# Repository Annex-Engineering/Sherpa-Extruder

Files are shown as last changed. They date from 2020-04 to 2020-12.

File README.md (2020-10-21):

# Sherpa - Release 1

This is the Sherpa Extruder, a ground up design developed by Anlin and the team at Annex Engineering. It's a family of dual geared hobbed filament extruders designed for use with any printer. They features a 6:1 gear driven design to provide torque while being able to be near silent. You must perform your own tuning to get the best results.

Our discord server can be found here: https://discord.gg/MzTR3zE

The BOM and Sourcing Guide for this product can be found here: https://docs.google.com/spreadsheets/d/1O3eyVuQ6M4F03MJSDs4Z71_XyNjXL5HFTZr1jsaAtRc/edit?usp=sharing

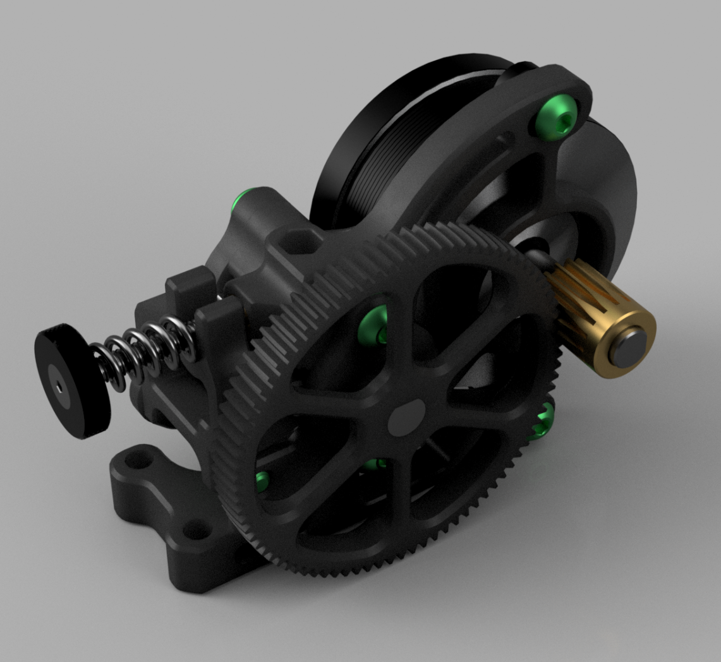
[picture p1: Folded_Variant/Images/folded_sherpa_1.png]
Image of Sherpa Extruder

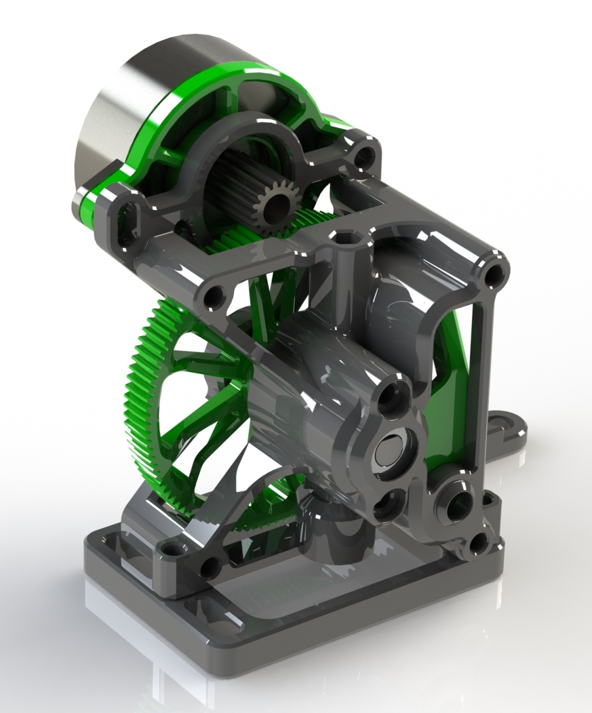
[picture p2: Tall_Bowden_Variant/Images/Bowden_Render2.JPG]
Image of Sherpa Extruder


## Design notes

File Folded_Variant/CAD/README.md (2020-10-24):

# Sherpa Folded

 - 103t was never really publicly released, but we are giving you the cad anyways. Consider it in a rough state
 
 - 85t is the actual final release 1, it is smaller and better in every way.

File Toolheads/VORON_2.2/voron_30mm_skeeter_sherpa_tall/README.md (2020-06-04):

This toolhead is for the Sherpa Standard Direct Drive Toolhead

30mm cooling fan for the mosquito

- requires 5 short m3 heat inserts

- Uses m3x30 screws to hold the fan and ducts on

- Uses same m2 plastite screws and fans from the original toolhead for the ducts

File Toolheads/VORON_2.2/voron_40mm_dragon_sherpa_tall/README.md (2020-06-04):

This toolhead is for the Sherpa Standard Direct Drive Toolhead

40mm cooling fan for the Dragon Hotend

- requires 5 short m3 heat inserts

- Uses m3x30 screws to hold the fan and ducts on

- Uses same m2 plastite screws and fans from the original toolhead for the ducts

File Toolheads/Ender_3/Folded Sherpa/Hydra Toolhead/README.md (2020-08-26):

# Ender 3 - Hydra Mount - Folded Sherpa Edition

This is a simple adaption of the head-part of the [Hydra Fanduct](https://www.thingiverse.com/thing:4062242) to fit a Folded Sherpa on the toolhead. 
Two versions exist - one for just the folded sherpa and a second version with additional support for a [carabiner-toolboard](https://github.com/Annex-Engineering/Annex_Engineering_PCBs/tree/master/carabiner-toolboard)

# Mounting Hardware

The following parts are required to mount a folded Sherpa on the head:
- 2x Heatset Inserts (M3xL4.0xD5.0)
- 1x M3x12mm Screw
- 1x M3x10mm Screw

The following parts are required in addition to the ones above mounting the carabiner on the mount:
- 2x Heatset Inserts (M3xL4.0xD5.0)
- 2xM3x8mm Screws (6mm are also ok)

# Adapting the .step files
Both versions of the toolhead have a .step / f3z-file provided to allow for simple adaption. 
The following parameters are intended to be adapted:
- HeatsetDiameter: Diameter of your heatset-inserts. If printing in ABS simpy insert the diameter of your heatset-inserts, otherwise substract 0.2mm
- ScrewHeadDiameter: Diameter of the countersunk screws. Provided 6mm is for m3 buttonhead screws
- ScrewHeadDepth: Depth for the countersunk screws. Provided 2mm is for m3 buttonhead screws.

## Attribution

The head is based & intended to be used with the great [Hydra Fanduct](https://www.thingiverse.com/thing:4062242) on an Ender3, designed by [BoothyBoothy](https://www.thingiverse.com/boothyboothy/designs)

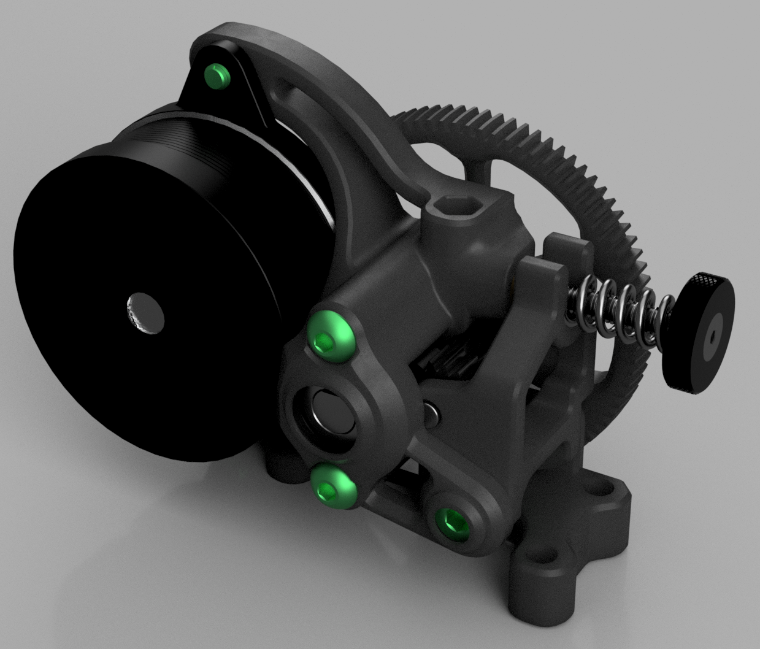
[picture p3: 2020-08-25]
Folded_Variant/Images/folded_sherpa_2.png

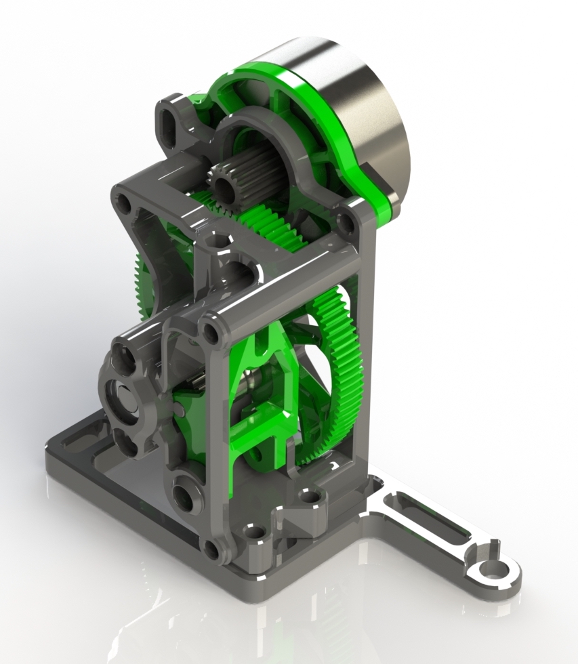
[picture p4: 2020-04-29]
Tall_Bowden_Variant/Images/Bowden_Render1.JPG

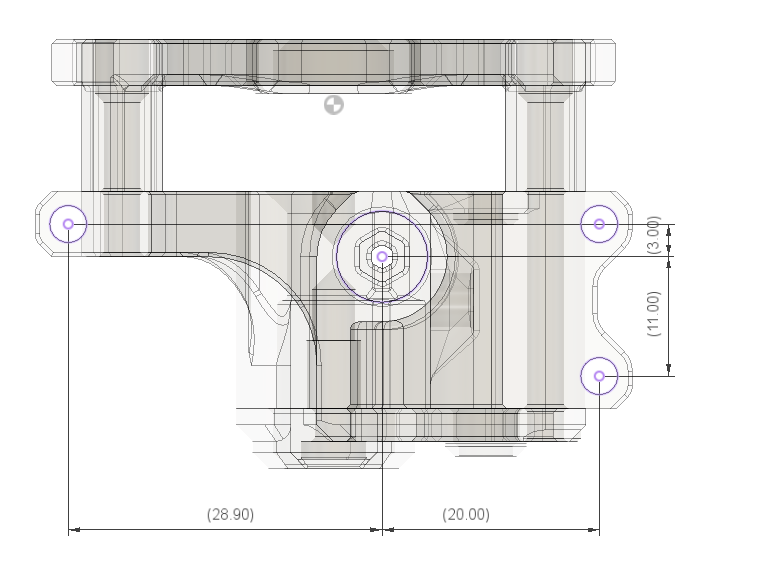
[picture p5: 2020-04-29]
Tall_Bowden_Variant/Documentation/mounting_pattern_top_down.PNG

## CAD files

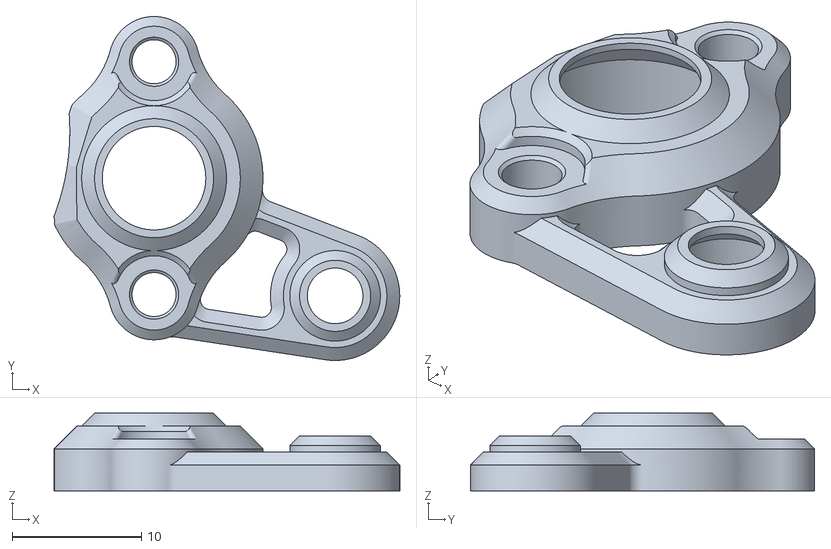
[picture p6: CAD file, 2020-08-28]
Folded_Variant/STLs/housing_front_x1_rev1.stl
26.7 x 26.6 x 6.00

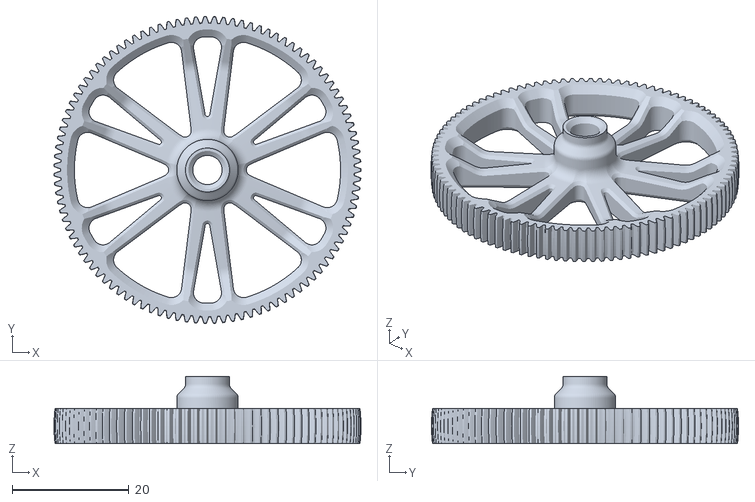
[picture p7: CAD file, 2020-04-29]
Tall_Bowden_Variant/STLs/[a}_103t_gear_v3_press_fit_5.0mm_id_no_flat_x1_rev1.stl
52.5 x 52.5 x 11.5

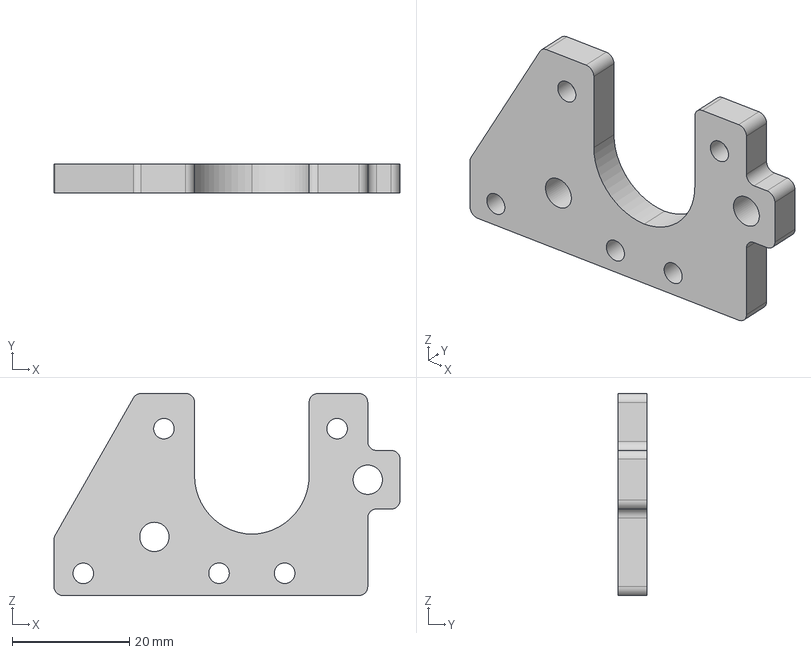
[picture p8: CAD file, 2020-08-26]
Toolheads/Ender_3/Folded Sherpa/Hydra Toolhead/STEPs/HydraHead-FoldedSherpa.step
59.0 x 5.00 x 34.5 mm

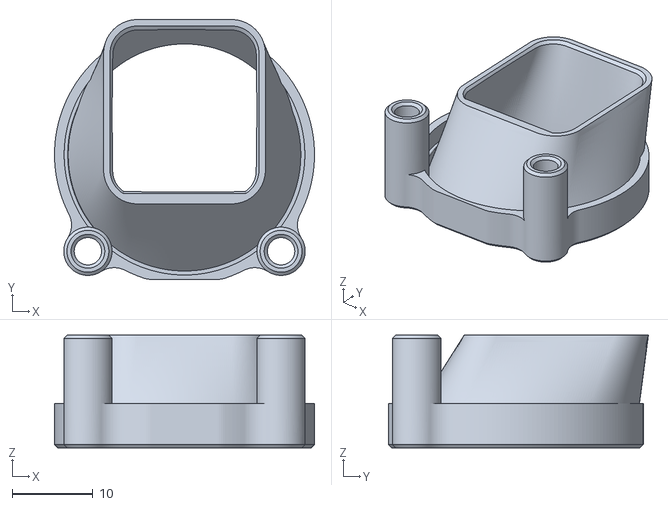
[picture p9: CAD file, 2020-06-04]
Toolheads/VORON_2.2/voron_30mm_skeeter_sherpa_tall/stls/[a]_30mm_skeeter_fan_duct_spacer_x1_rev2.stl
32.3 x 32.3 x 14.0

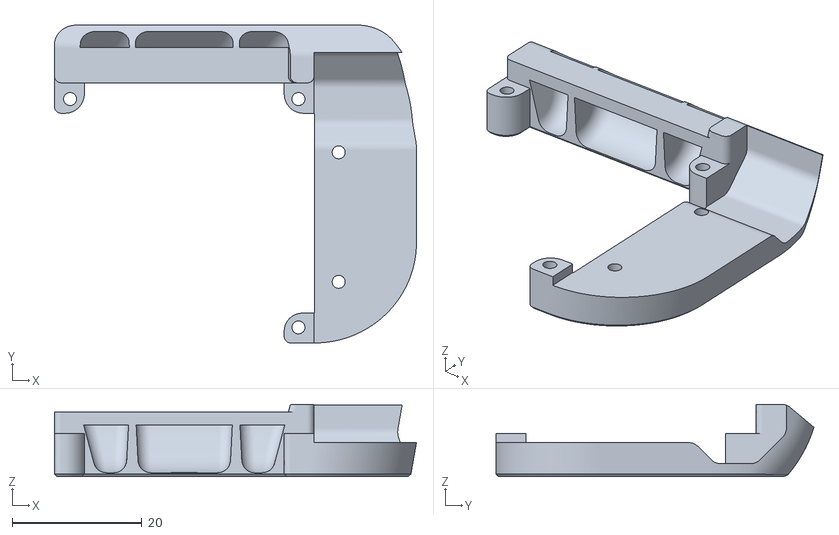
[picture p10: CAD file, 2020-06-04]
Toolheads/VORON_2.2/voron_40mm_dragon_sherpa_tall/stls/[a]_40mm_dragon_left_duct_x1_rev1.stl
55.8 x 49.0 x 11.1

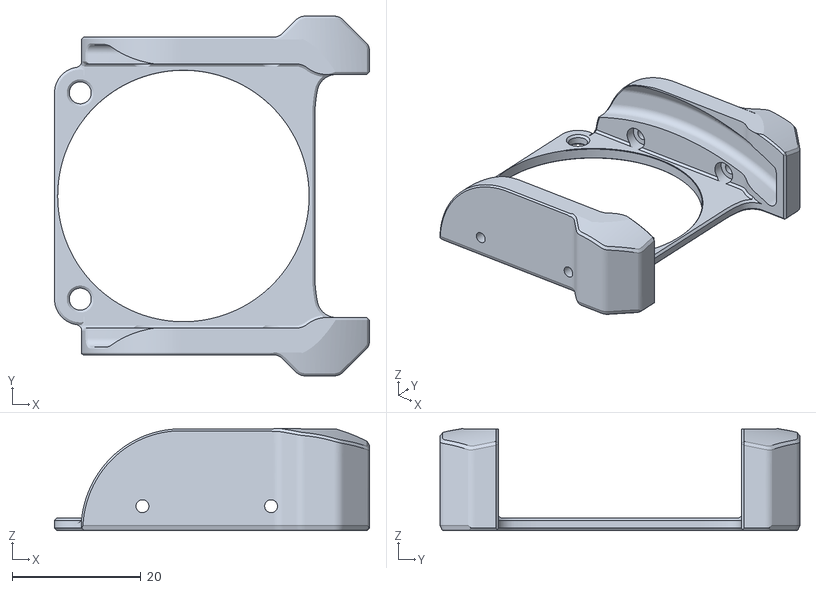
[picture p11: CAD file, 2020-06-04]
Toolheads/VORON_2.2/voron_40mm_skeeter_sherpa_tall/stl/40mm_skeeter_fan_holder_x1_rev1.stl
48.9 x 55.8 x 15.9

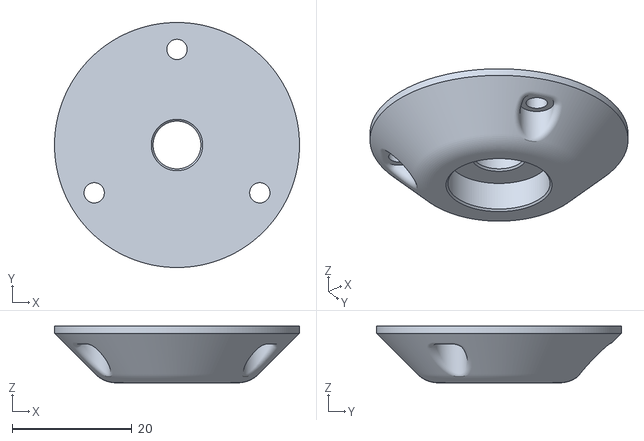
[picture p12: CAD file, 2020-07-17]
Tools/STLs/gear_shaft_pressing_tool_bottom_optional_x1_rev1.stl
41.0 x 41.0 x 9.50

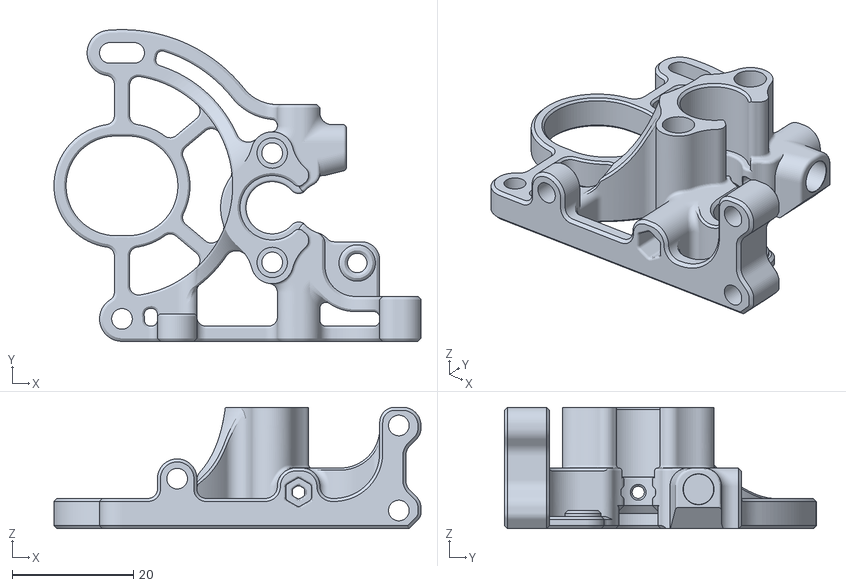
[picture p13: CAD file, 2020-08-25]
Folded_Variant/STLs/housing_core_dd_x1_rev1.stl
60.4 x 51.3 x 20.0

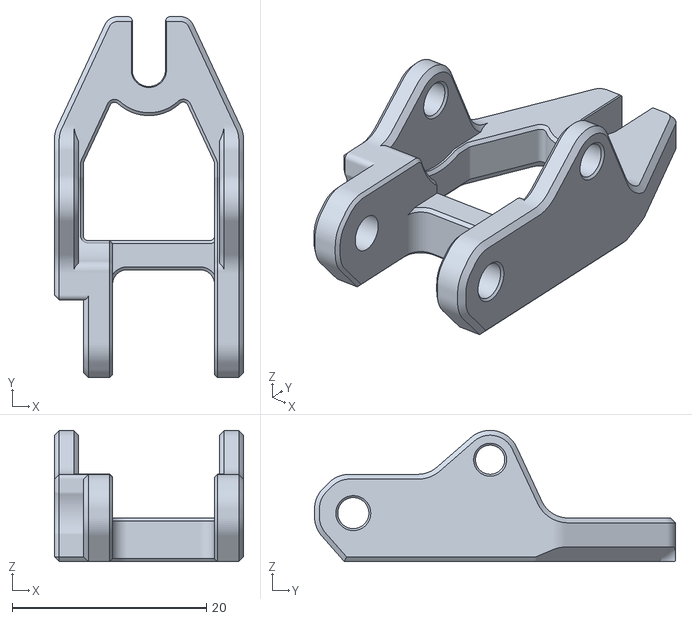
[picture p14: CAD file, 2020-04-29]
Tall_Direct_Drive_Variant/STLs/[a}_idler_carrier_x1_rev1.stl
19.5 x 37.2 x 13.5

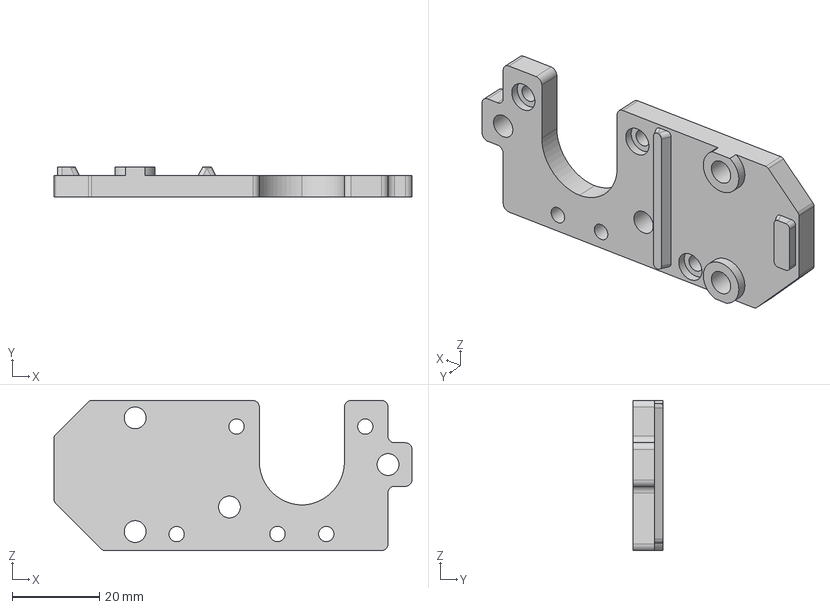
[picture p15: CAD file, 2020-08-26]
Toolheads/Ender_3/Folded Sherpa/Hydra Toolhead/STEPs/HydraHead-Carabiner-FoldedSherpa.step
82.2 x 7.00 x 34.5 mm

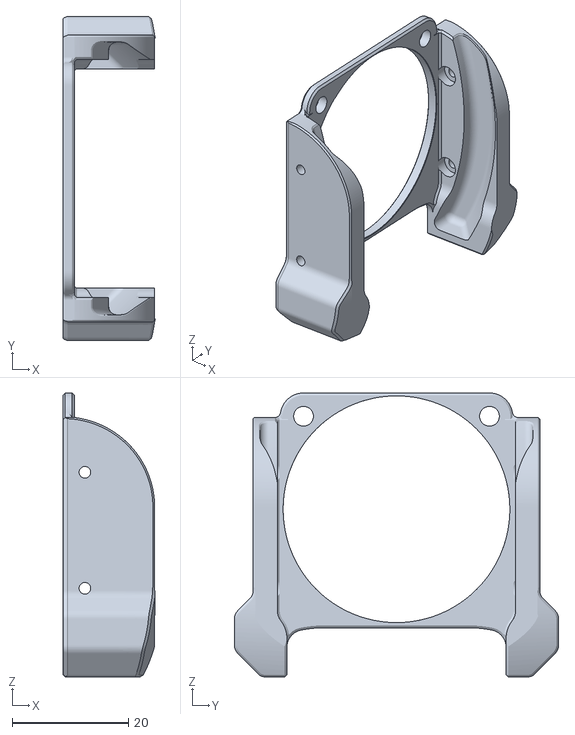
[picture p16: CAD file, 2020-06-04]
Toolheads/VORON_2.2/voron_40mm_dragon_sherpa_tall/stls/40mm_dragon_fan_holder_x1_rev1.stl
15.9 x 55.8 x 48.9

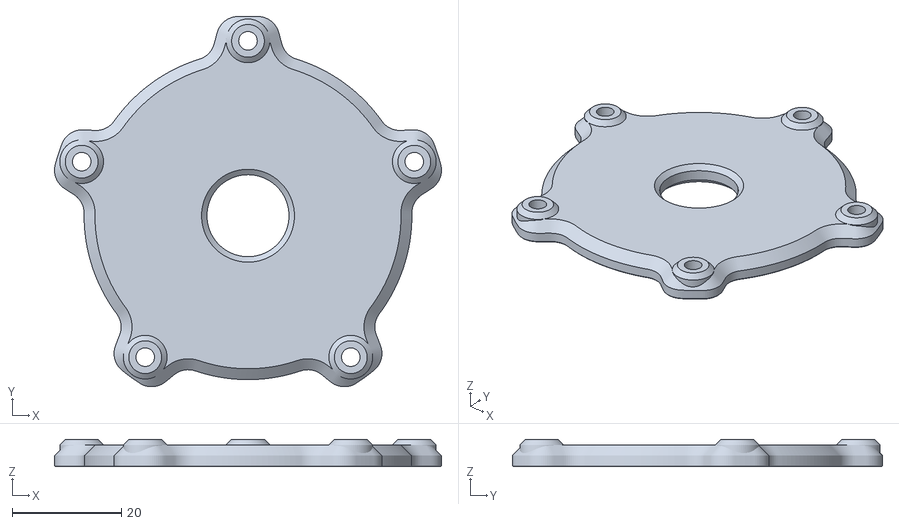
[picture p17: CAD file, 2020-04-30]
Tools/STLs/gear_shaft_pressing_tool_top_x1_rev1.stl
70.8 x 67.8 x 5.00

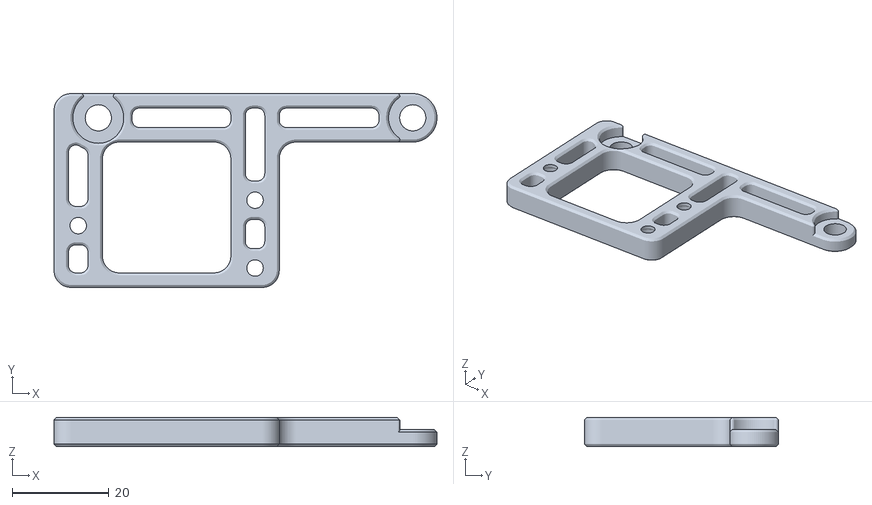
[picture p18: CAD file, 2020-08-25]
Folded_Variant/STLs/rappel_adapter_x1_rev1.stl
79.1 x 40.0 x 6.00

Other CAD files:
Tall_Direct_Drive_Variant/STLs/[a}_103t_gear_v5_press_fit_5.0mm_id_0.4mm_flat_x1_rev1.stl
Tall_Bowden_Variant/STLs/[a}_103t_gear_v5_press_fit_5.0mm_id_0.4mm_flat_x1_rev1.stl
Toolheads/VORON_2.2/voron_30mm_skeeter_sherpa_tall/stls/[a]_left_duct_x1_rev1.stl
Toolheads/VORON_2.2/voron_40mm_skeeter_sherpa_tall/stl/[a]_right_duct_x1_rev1.stl
Folded_Variant/STLs/85t_rounded_spur_gear_0.5mm_flat_x1_rev1.stl
Folded_Variant/STLs/85t_rounded_spur_gear_no_flat_x1_rev1.stl
Folded_Variant/STLs/housing_core_bowden_x1_rev1.stl
Folded_Variant/STLs/idler_carrier_x1_rev1.stl
Folded_Variant/STLs/rear_bearing_retainer_x1_rev1.stl
Tall_Bowden_Variant/STLs/[a}_103t_gear_v5_press_fit_5.0mm_id_0.5mm_flat_x1_rev1.stl
Tall_Bowden_Variant/STLs/[a}_nema16_17_adapter_plate_7mm_x1_rev1.stl
Tall_Bowden_Variant/STLs/housing_core_bowden_x1_rev1.stl
Tall_Bowden_Variant/STLs/housing_front_x1_rev1.stl
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

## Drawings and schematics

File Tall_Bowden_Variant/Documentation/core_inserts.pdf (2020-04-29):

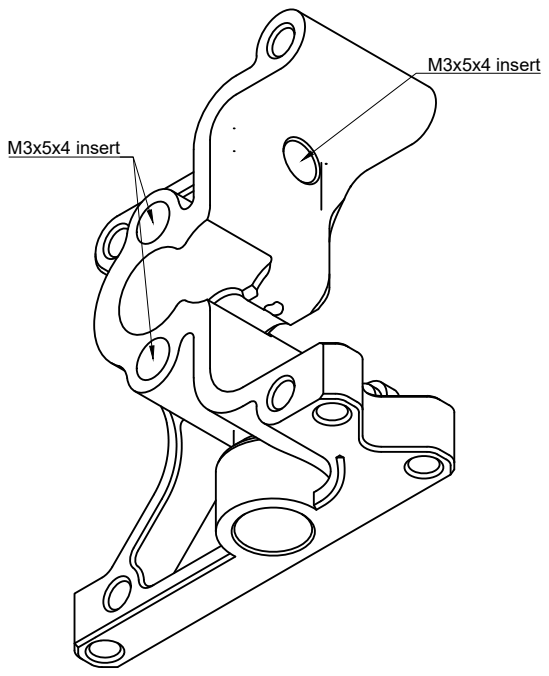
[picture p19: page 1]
M3x5x4 insert

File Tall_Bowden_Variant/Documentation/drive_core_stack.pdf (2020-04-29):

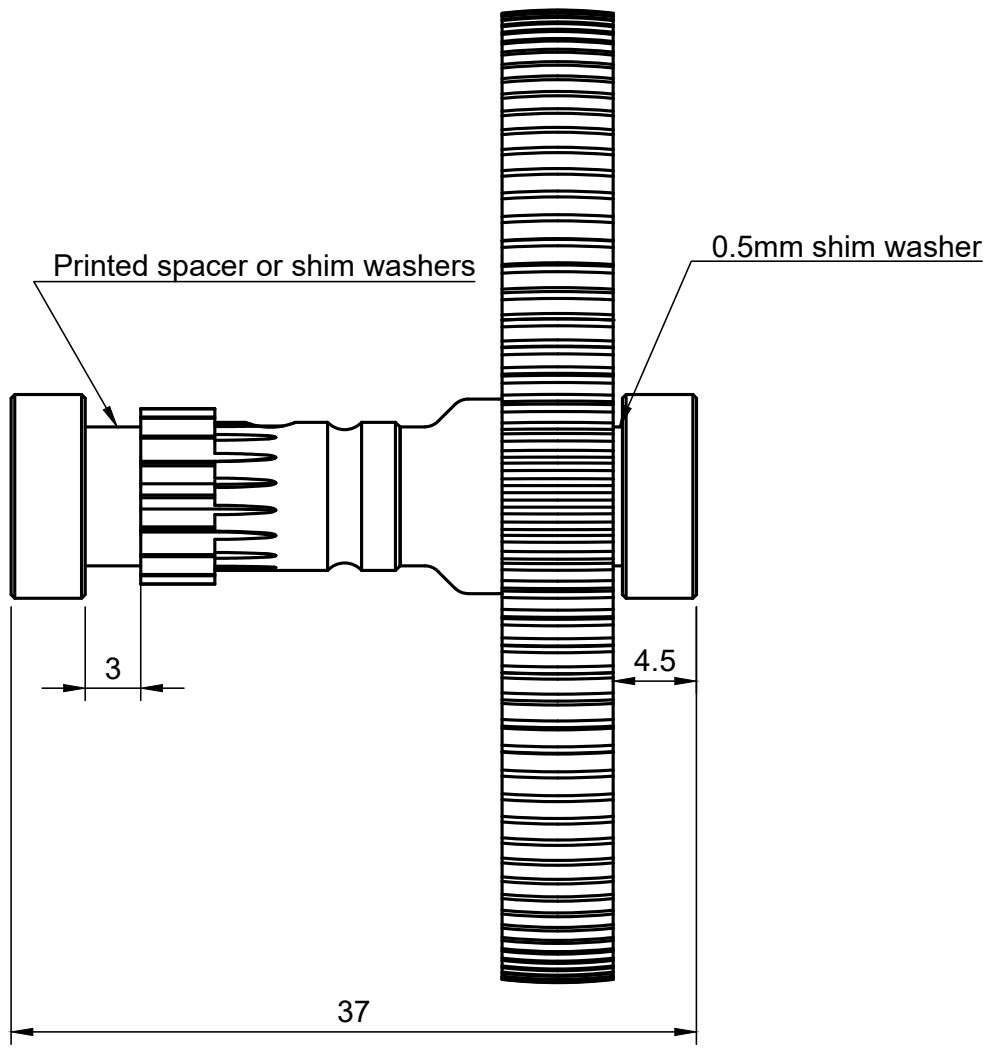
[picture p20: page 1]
Printed spacer or shim washers; 0.5mm shim washer

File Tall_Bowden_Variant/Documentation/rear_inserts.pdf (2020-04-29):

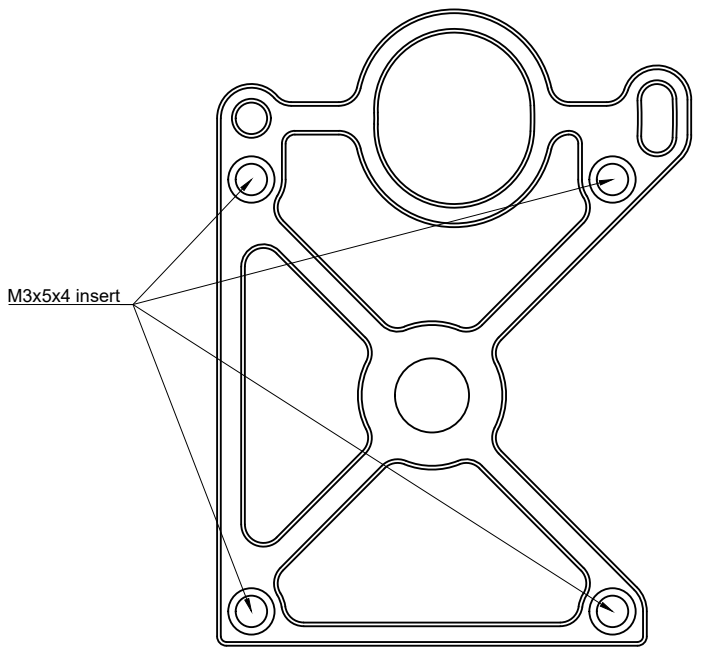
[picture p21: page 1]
M3x5x4 insert

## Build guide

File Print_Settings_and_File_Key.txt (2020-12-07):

Primary Color: nothing at start of file name
Accent Color: [a]_ at start of file name
Quantity Required: _x# near end of file name
File Revision: _Rev# at end of file name

Nozzle Size: 0.4 or 0.6mm Recommended
Recommended FDM Materials: ASA, Polymaker or 3DXTech Recommended
Alternate Approved FDM Materials: ABS, ABS+, 3DXtech or Atomic Filaments Recommended
Layer Height: 0.1mm or 0.2mm
Extrusion Width: Forced 0.4mm
Infill Percentage: 40% minimum (at 0.6mm Width)
Infill Type: Grid, Gyroid, Honeycomb, Triangle or Cubic
Wall Count: 3 minimum (at 0.4mm Width)
Solid Top/Bottom Layers: 5 minimum (at 0.2mm Height)

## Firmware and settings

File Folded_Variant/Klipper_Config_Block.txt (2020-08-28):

These are good starting settings for the extruder, I have copy pasted my entire block out of my klipper config below:

# Extruder0
[extruder]
"5:1" gears, dd, shaft nema14 with 17t gear on it
step_distance: 0.001423

#0.4mm Nozzle
nozzle_diameter: 0.400
pressure_advance: 0.05
pressure_advance_smooth_time: 0.040
max_extrude_only_distance: 1400.0
max_extrude_only_velocity: 30.0
max_extrude_only_accel: 100.0
max_extrude_cross_section: 20000.0 #this is for KISSlicer Only

#settings for NEMA14 Stepper
[tmc2209 extruder]
microsteps: 16
interpolate: false
run_current: 0.25 #up to 0.3A

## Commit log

2020-04-29 first release
    [103t_gear_v3_press_fit_5.0mm_id_no_flat.stl, 103t_gear_v5_press_fit_5.0mm_id_0.4mm_flat.stl, 103t_gear_v5_press_fit_5.0mm_id_0.5mm_flat.stl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]
2020-04-30 add preliminary gear install tool, remove parts not currently used and parts that were in wrong folder
    [[a}_103t_gear_v3_press_fit_5.0mm_id_no_flat_x1_rev1.stl, [a}_103t_gear_v5_press_fit_5.0mm_id_0.4mm_flat_x1_rev1.stl, [a}_103t_gear_v5_press_fit_5.0mm_id_0.5mm_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]
2020-06-04 add DD variant and DD toolheads for VORON2
    add DD variant and DD toolheads for VORON2
    [30mm_skeeter_fan_holder_x1_rev1.stl, 30mm_skeeter_toolhead_x1_rev2.stl, 40mm_dragon_fan_holder_x1_rev1.stl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]
2020-07-17 Add 3rd bearing to pressing tool
    [gear_shaft_pressing_tool_base_x1_rev1.stl, gear_shaft_pressing_tool_bottom_optional_x1_rev1.stl]
2020-08-15 reorg to make room for folded variant
    [30mm_skeeter_fan_holder_x1_rev1.stl, 30mm_skeeter_toolhead_x1_rev2.stl, 40mm_dragon_fan_holder_x1_rev1.stl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]
2020-08-25 add folded sherpa stls and renders
    [85t_rounded_spur_gear_0.5mm_flat_x1_rev1.stl, 85t_rounded_spur_gear_no_flat_x1_rev1.stl, housing_core_bowden_x1_rev1.stl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]
2020-08-26 Adding the Hydra Mount for Folded Sherpa on the Ender3.
    [HydraHead-Carabiner-FoldedSherpa.f3z, HydraHead-Carabiner-FoldedSherpa.step, HydraHead-Carabiner-FoldedSherpa.stl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]
2020-08-26 reorg toolheads
    [30mm_skeeter_fan_holder_x1_rev1.stl, 30mm_skeeter_toolhead_x1_rev2.stl, 40mm_dragon_fan_holder_x1_rev1.stl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]
2020-08-28 update klipper config blocks
    [Klipper_Config_Block.txt]
2020-08-28 update print settings.txt
2020-08-28 Create housing_front_x1_rev1.stl
    Add missing front housing
    [housing_front_x1_rev1.stl]
2020-10-21 add cad files for sherpa tall and folded
2020-10-24 add 85t cad, 103 was actually an old variant that was never publicly released
2020-12-07 update print settings files
